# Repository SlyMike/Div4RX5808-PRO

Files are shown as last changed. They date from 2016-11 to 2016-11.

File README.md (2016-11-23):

# Div4RX5808-PRO
Arduino based 5.8GHz  Diversity Video receiver using 2x RX5808-PRO RX modules.

This project requires that you make 3 seperate PCB's. Two RX5808-PRO enabled video RX modules and a Diversity main board.
Boards and schematics are supplied for both the receivers and mainboard. 
Boards and schematics are in Eagle PCB format.

The RX modules will need to be assembled and programmed with the RX5808-PRO software (available on Github).
The diversity code for the Main board is available within this repository. After downloading, replace the .C file extension with .ino and upload.

The Main board and RX modules will require an Arduino Nano with an Atmega328.

The software portion of this project is not an adaptation of RX5808-PRO, it's function is to monitor 2x RSSI inputs from 2x RX5808-PRO enabled receivers and display the video feed from the receiver with the better signal. 
Video, audio and controls are switched simultaniously. LEDs indicate RSSI percentage (4 LEDs), active receiver (2 LEDs) and diversity mode (1 LED).

Holding the "Video" button during boot will allow for RSSI calibration as many RX5808 modules will have slightly different lower and upper limits.
The Div4RX5808-PRO diversity video receiver will assume that channel selection is correct and that nobody else is using the chosen channel.
The transmitter on the RC model should be set to the same channel as the receiver, the model should be powered down.

(1) Turn on Div4RX5808-PRO diversity video receiver in RSSI calibration mode (TX OFF). Amber led indicates LOW RSSI calculation. Press and release "Mode" button.
(2) Turn on transmitter. Second amber led indicates HIGH RSSI calculation. Press and release "Mode" button.
(3) Green LED indicates a good calibration, red a failure.

Auto calibration may not be necessary and if it is not initiated on power up (or fails for some reason), received RSSI values will be directly compared as if limits are equal on both modules.

Hold the "Mode" button during power up to enable serial debug output.

The code has been tested to a degree, it seems to work for me but there is always room for improvement.
I consider this project a work in progress, you may find bugs, spelling mistakes, missing component values, most of the source files were made in a rush or whilst I was doing something else.

I may address this in future but for most folk it should not be hard to build.

The point of this project was to create a decent micro controlled diversity receiver with better features than some of the crude homebrew solutions that I found on the net. I'm pretty sure I met my goal!

      FEATURES:
      
      *** AUTO RSSI CALIBRATION ***
      
      RX5808-PRO SUPPORT.
      
      LIVE VIDEO / SPECTRUM ANALYSER SWITCHING VIA PUSH BUTTON.
      SINGLE RX OR DIVERSITY MODES VIA PUSH BUTTON.
      SERIAL DEBUG MODE VIA PUSH BUTTON.
      TOTAL 6 PUSH BUTTONS FOR EASY OPERATION.
      SOFTWARE SWITCH DE-BOUNCING.
      
      MODE LED INDICATORS.
      RSSI LED INDICATORS.
      RX LED INDICATORS.
      
      VARIABLE RSSI SMOOTHING.
      VARIABLE RX SWITCHING RATE.
      VARIABLE RSSI HYSTERESIS.
      
      CHOICE OF VOLTAGE REFERENCE METHODS - CODE WILL WORK ON 3V3 AND 5V TARGETS.
      WELL COMMENTED CODE.

I hope you find this project helpful, maybe it's worth a coffee?              


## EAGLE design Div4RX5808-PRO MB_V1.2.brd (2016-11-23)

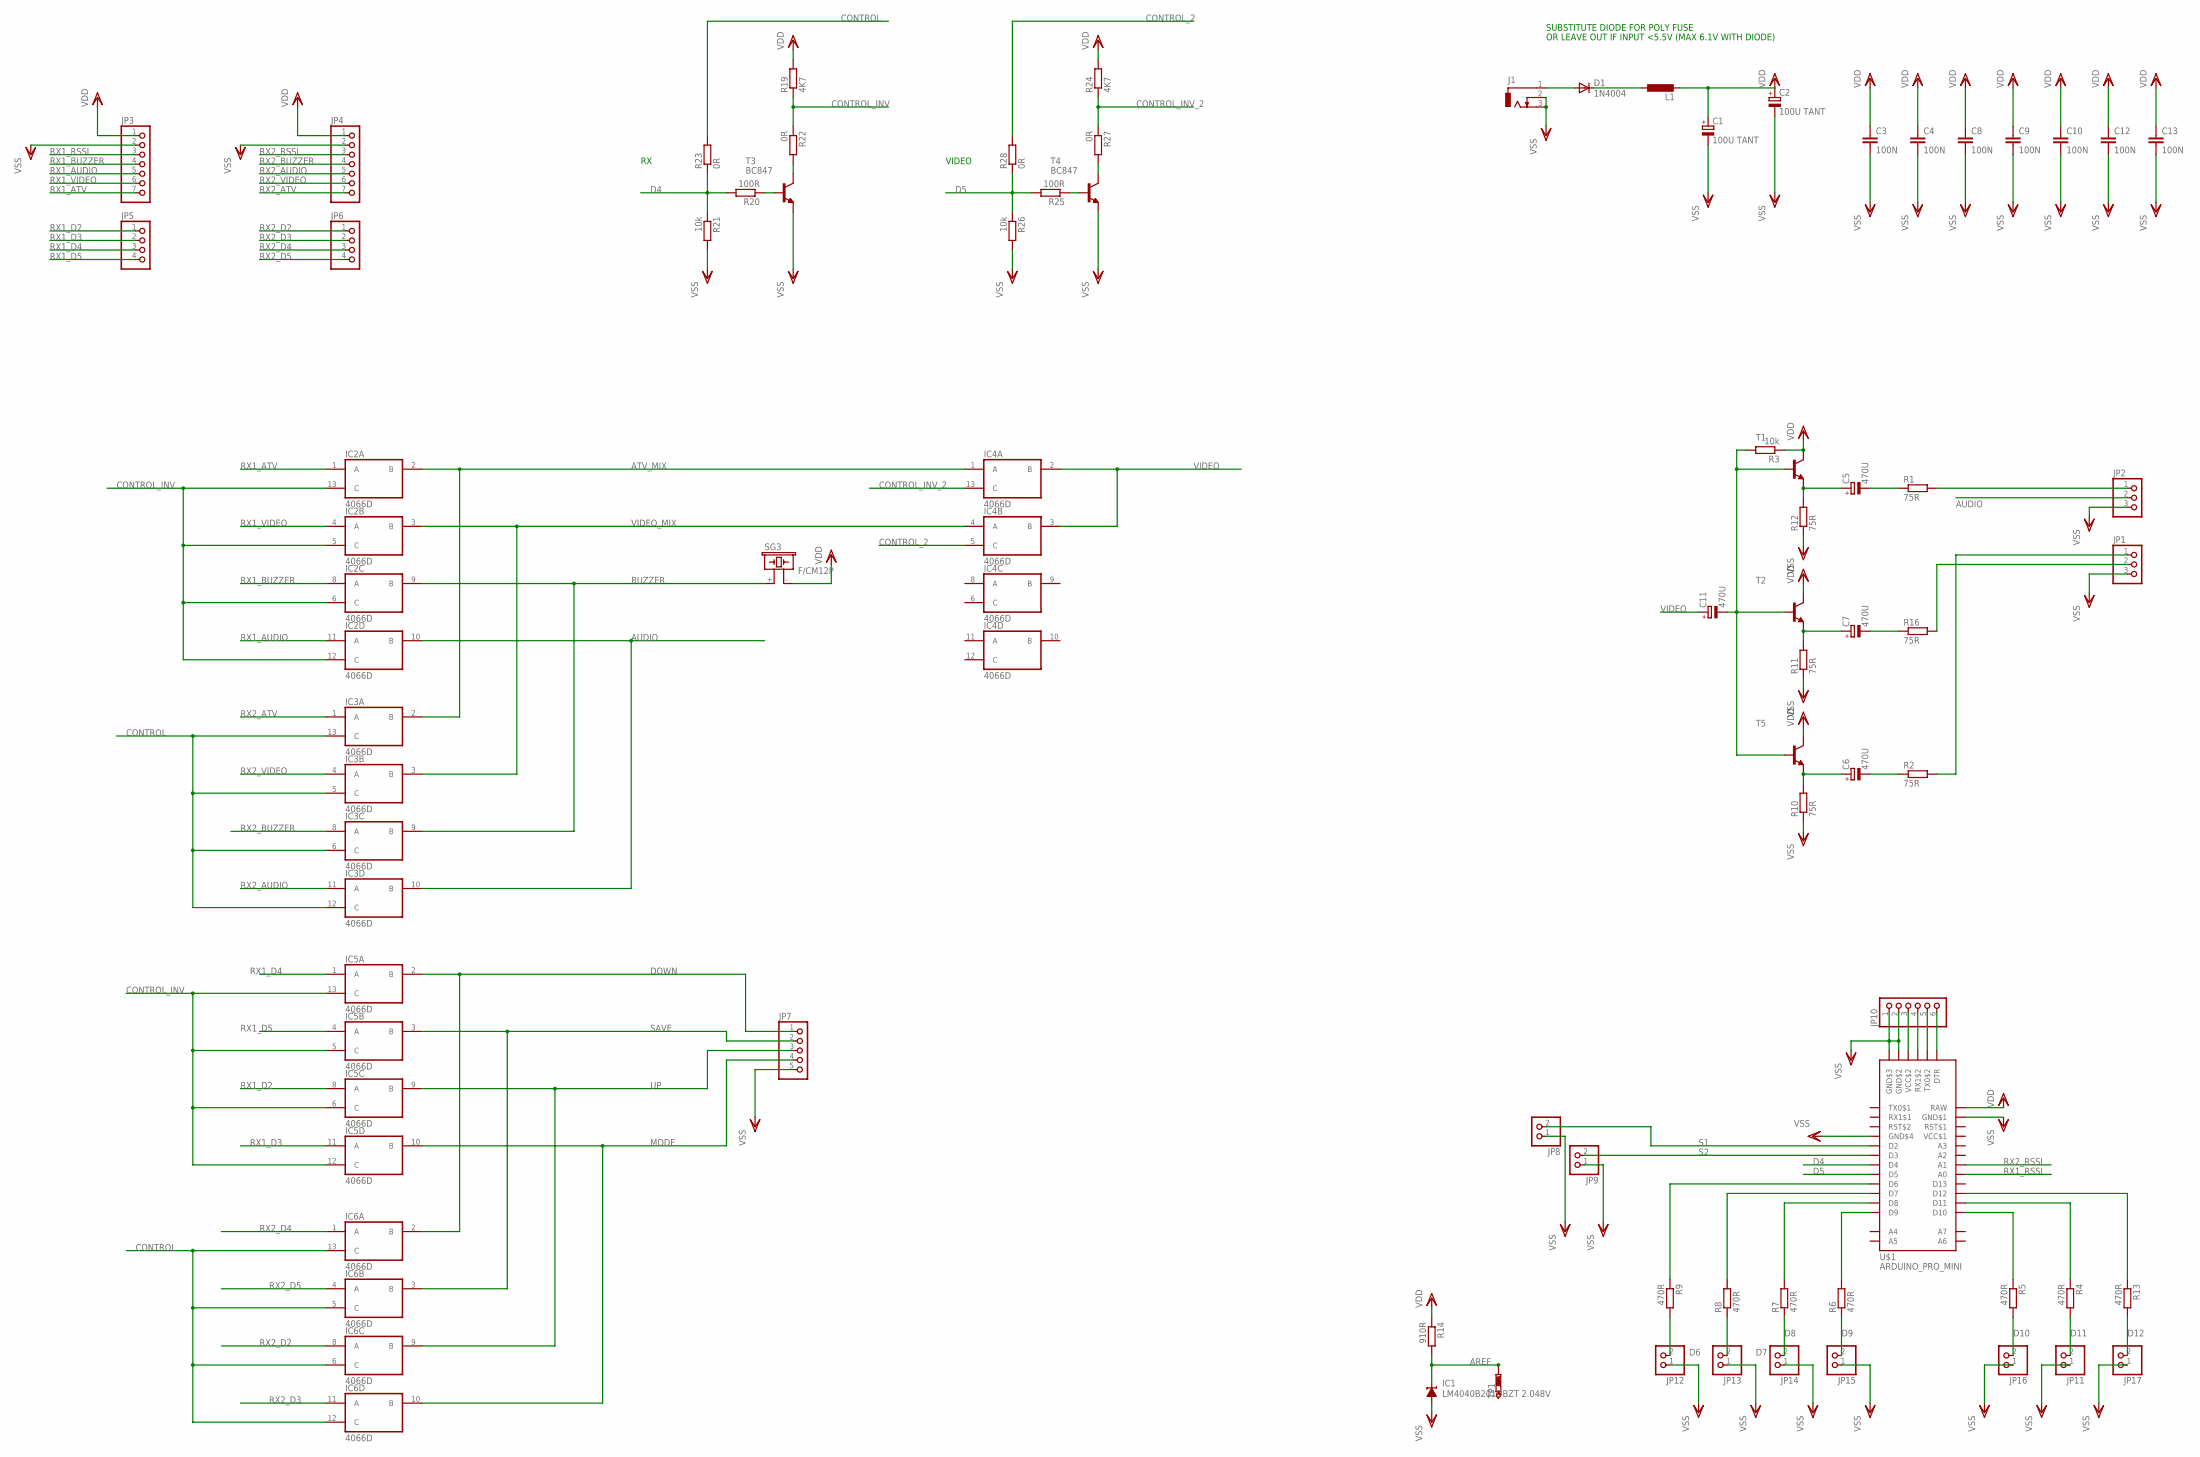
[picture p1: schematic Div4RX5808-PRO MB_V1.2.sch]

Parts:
C1, C2: 100U TANT; C/6032-28R
C3, C4, C8, C9, C10, C12, C13: 100N; C0603
C5, C6, C7, C11: 470U; E5-10,5
D1: 1N4004; DO41-10
IC1: LM4040B201DBZT 2.048V; DBZ_R-PDSO-G3
IC2, IC3, IC4, IC5, IC6: 4066D; SO14
J1: DCJ0303
JP1, JP2: PINHD-1X3; 1X03
JP3, JP4: PINHD-1X7; 1X07
JP5, JP6: PINHD-1X4; 1X04
JP7: PINHD-1X5; 1X05
JP8, JP9, JP11, JP12, JP13, JP14, JP15, JP16, JP17: PINHD-1X2; 1X02
JP10: PINHD-1X6; 1X06
L1: L-EU0207/7; 0207/7
R1, R2, R10, R11, R12, R16: 75R; M0805
R3, R21, R26: 10k; M0805
R4, R5, R6, R7, R8, R9, R13: 470R; R0603
R14: 910R; R0603
R19, R24: 4K7; M0805
R20, R25: 100R; M0805
R22, R23, R27, R28: 0R; M0805
SG3: F/CM12P
T1, T2, T5: MMBT2222ALT1-NPN-SOT23-BEC; SOT23-BEC
T3, T4: BC847; SOT23-BEC
TP1: PTR1TP20SQ; TP20SQ
U$1: ARDUINO_PRO_MINI

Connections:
AREF: IC1.1 (C), R14.2, TP1.TP
ATV_MIX: IC2.2 (B), IC3.2 (B), IC4.1 (A)
AUDIO: IC2.10 (B), IC3.10 (B), JP2.2
BUZZER: IC2.9 (B), IC3.9 (B), SG3.+ (1)
CONTROL: IC3.5 (C), IC3.6 (C), IC3.12 (C), IC3.13 (C), IC6.5 (C), IC6.6 (C), IC6.12 (C), IC6.13 (C), R23.2
CONTROL_2: IC4.5 (C), R28.2
CONTROL_INV: IC2.5 (C), IC2.6 (C), IC2.12 (C), IC2.13 (C), IC5.5 (C), IC5.6 (C), IC5.12 (C), IC5.13 (C), R19.1, R22.1
CONTROL_INV_2: IC4.13 (C), R24.1, R27.1
D4: R20.2, R21.1, R23.1, U$1.D4
D5: R25.2, R26.1, R28.1, U$1.D5
D6: JP12.2, R9.2
D7: JP13.2, R8.1
D8: JP14.2, R7.1
D9: JP15.2, R6.1
D10: JP16.2, R5.2
D11: JP11.2, R4.2
D12: JP17.2, R13.2
DOWN: IC5.2 (B), IC6.2 (B), JP7.1
MODE: IC5.10 (B), IC6.10 (B), JP7.4
unnamed: D1.C, L1.1
unnamed: D1.A, J1.1
unnamed: R13.1, U$1.D12
unnamed: C5.-, R1.1
unnamed: C6.-, R2.1
unnamed: JP2.1, R1.2
unnamed: C7.-, R16.1
unnamed: JP1.2, R16.2
unnamed: JP1.1, R2.2
unnamed: C5.+, R12.2, T1.E
unnamed: JP10.6, U$1.DTR
unnamed: JP10.5, U$1.TX0$2
unnamed: C7.+, R11.2, T2.E
unnamed: JP10.4, U$1.RX1$2
unnamed: JP10.3, U$1.VCC$2
unnamed: R25.1, T4.B
unnamed: C6.+, R10.2, T5.E
unnamed: R22.2, T3.C
unnamed: R20.1, T3.B
unnamed: R27.2, T4.C
unnamed: C11.-, R3.2, T1.B, T2.B, T5.B
unnamed: R9.1, U$1.D6
unnamed: R8.2, U$1.D7
unnamed: R6.2, U$1.D9
unnamed: R4.1, U$1.D11
unnamed: R5.1, U$1.D10
unnamed: R7.2, U$1.D8
RX1_ATV: IC2.1 (A), JP3.7
RX1_AUDIO: IC2.11 (A), JP3.5
RX1_BUZZER: IC2.8 (A), JP3.4
RX1_D2: IC5.8 (A), JP5.1
RX1_D3: IC5.11 (A), JP5.2
RX1_D4: IC5.1 (A), JP5.3
RX1_D5: IC5.4 (A), JP5.4
RX1_RSSI: JP3.3, U$1.A0
RX1_VIDEO: IC2.4 (A), JP3.6
RX2_ATV: IC3.1 (A), JP4.7
RX2_AUDIO: IC3.11 (A), JP4.5
RX2_BUZZER: IC3.8 (A), JP4.4
RX2_D2: IC6.8 (A), JP6.1
RX2_D3: IC6.11 (A), JP6.2
RX2_D4: IC6.1 (A), JP6.3
RX2_D5: IC6.4 (A), JP6.4
RX2_RSSI: JP4.3, U$1.A1
RX2_VIDEO: IC3.4 (A), JP4.6
S1: JP8.2, U$1.D2
S2: JP9.2, U$1.D3
SAVE: IC5.3 (B), IC6.3 (B), JP7.2
UP: IC5.9 (B), IC6.9 (B), JP7.3
VCC$1: U$1.VCC$1
VDD: C1.+, C2.+, C3.1, C4.1, C8.1, C9.1, C10.1, C12.1, C13.1, IC2.14 (VDD), IC3.14 (VDD), IC4.14 (VDD), IC5.14 (VDD), IC6.14 (VDD), JP3.1, JP4.1, L1.2, R3.1, R14.1, R19.2, R24.2, SG3.- (2), T1.C, T2.C, T5.C, U$1.RAW
VIDEO: C11.+, IC4.2 (B), IC4.3 (B)
VIDEO_MIX: IC2.3 (B), IC3.3 (B), IC4.4 (A)
VSS: C1.-, C2.-, C3.2, C4.2, C8.2, C9.2, C10.2, C12.2, C13.2, IC1.2 (A), IC2.7 (VSS), IC3.7 (VSS), IC4.7 (VSS), IC5.7 (VSS), IC6.7 (VSS), J1.2, J1.3, JP1.3, JP2.3, JP3.2, JP4.2, JP7.5, JP8.1, JP9.1, JP10.1, JP10.2, JP11.1, JP12.1, JP13.1, JP14.1, JP15.1, JP16.1, JP17.1, R10.1, R11.1, R12.1, R21.2, R26.2, T3.E, T4.E, U$1.GDN$1 (GND$1), U$1.GND$2, U$1.GND$3, U$1.GND$4

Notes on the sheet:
VIDEO
SUBSTITUTE DIODE FOR POLY FUSE
OR LEAVE OUT IF INPUT <5.5V (MAX 6.1V WITH DIODE)

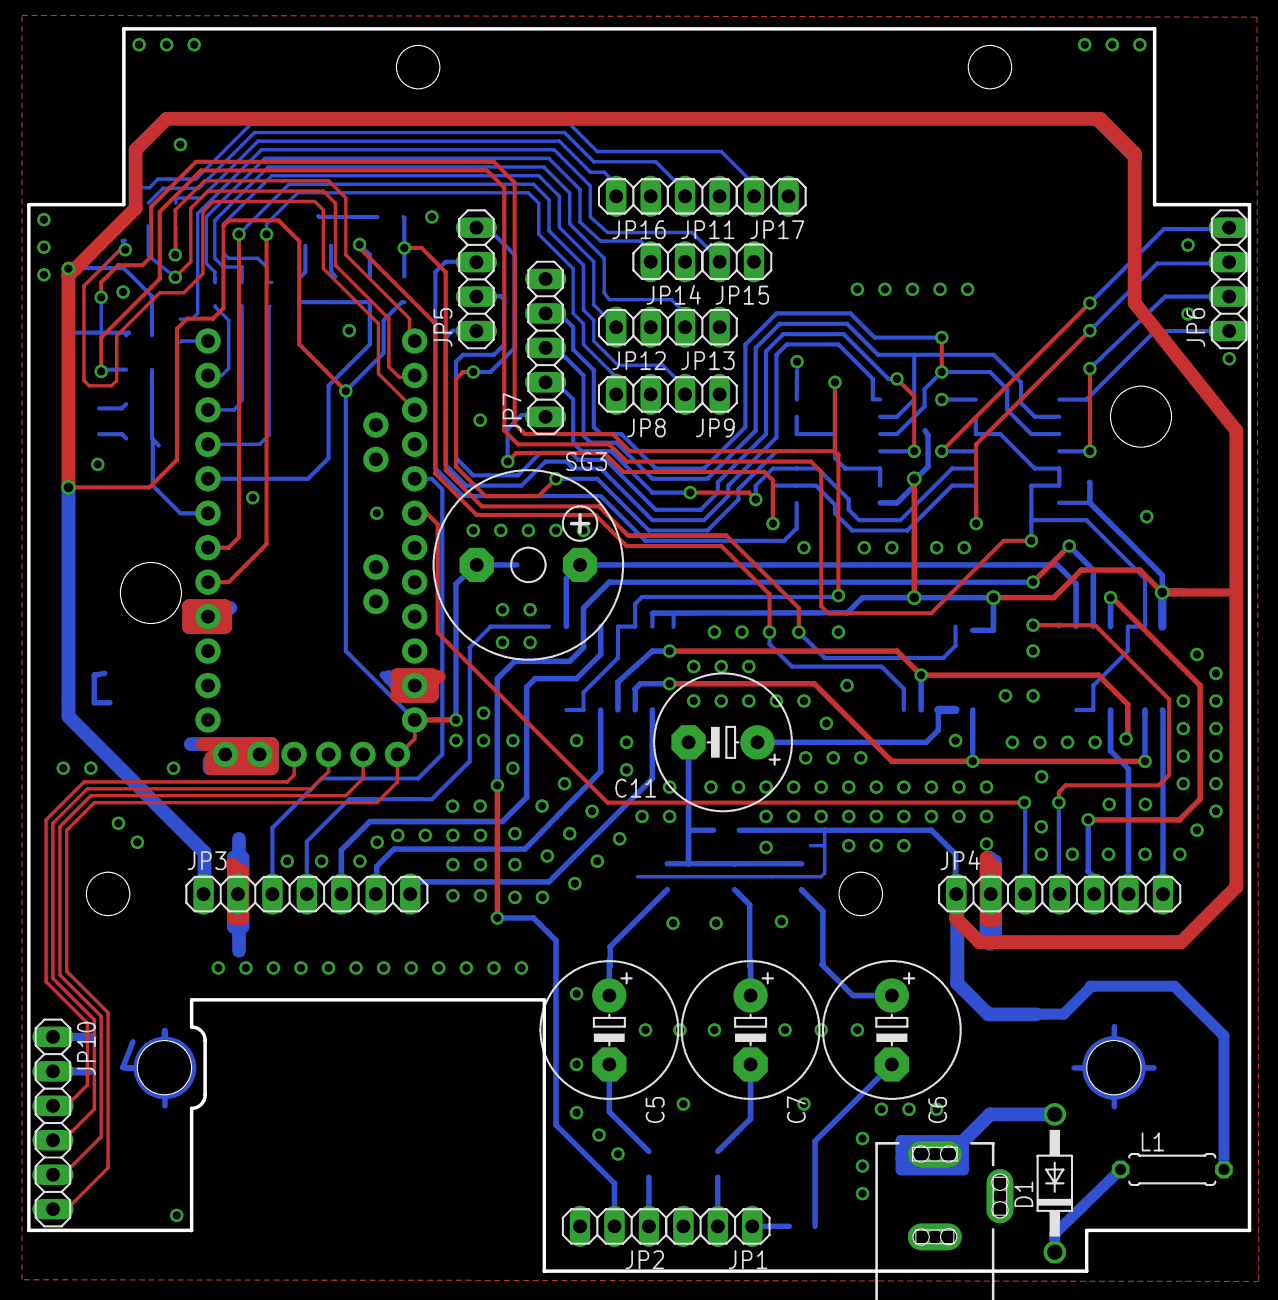
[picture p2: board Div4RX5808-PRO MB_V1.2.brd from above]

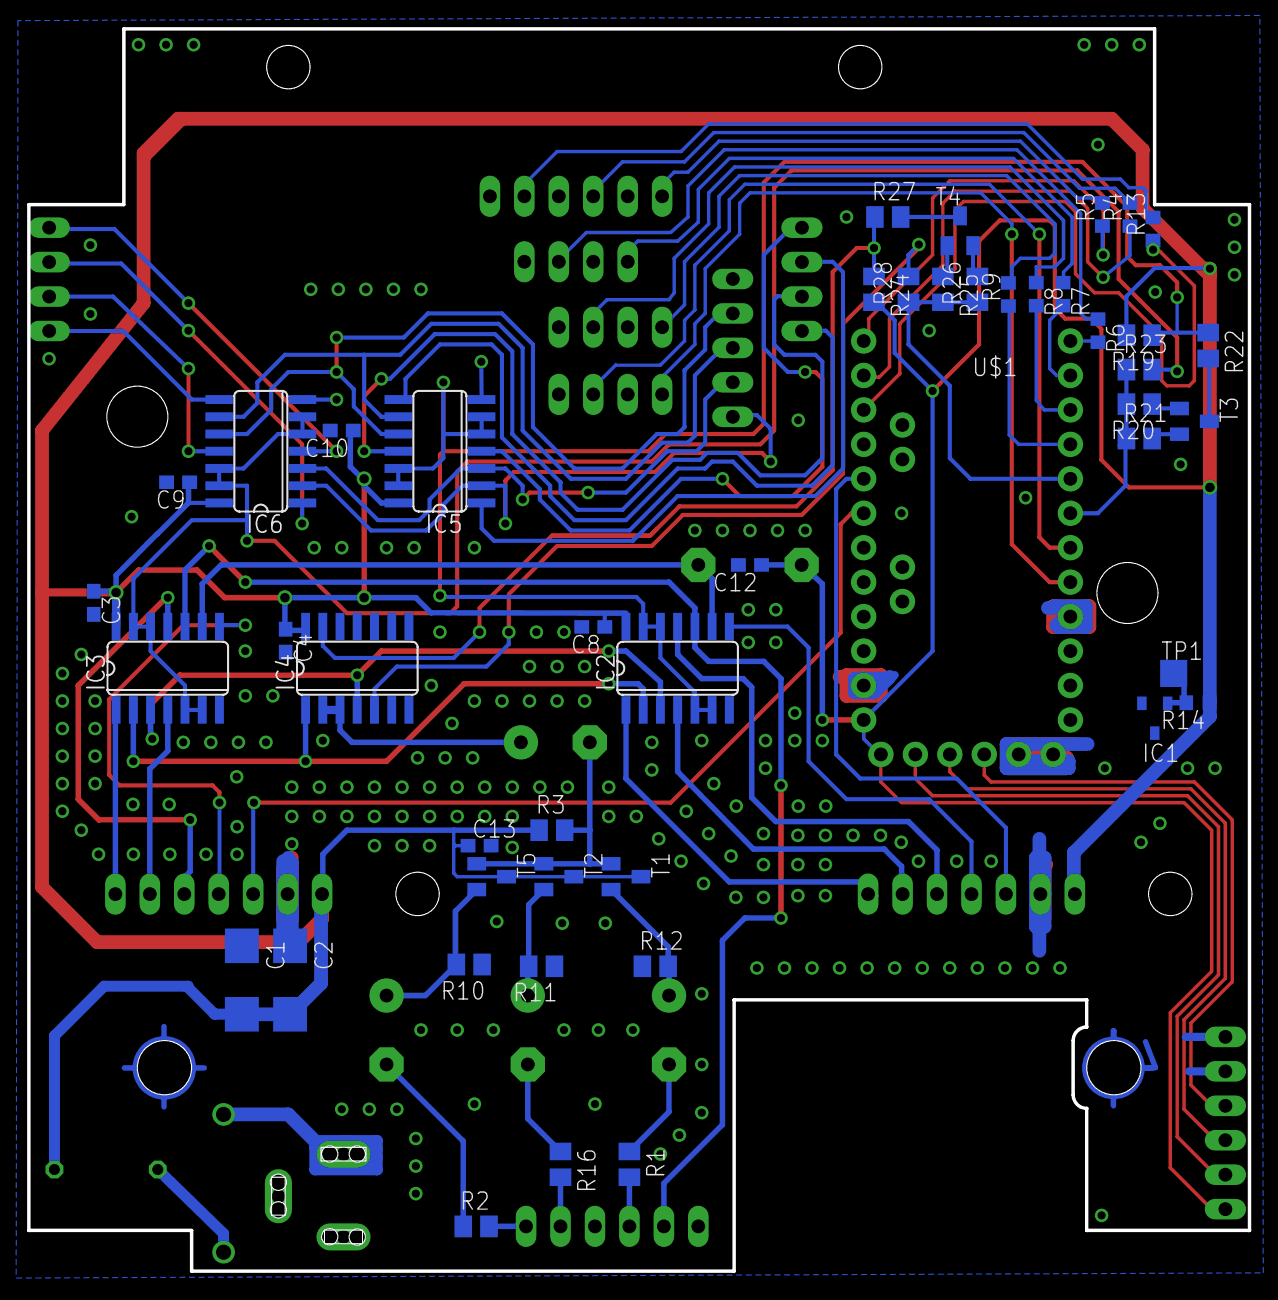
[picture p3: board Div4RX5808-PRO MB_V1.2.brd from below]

Board: 2 copper layers, 90.0 x 91.6 mm, 72 parts (47 on the bottom side), 72 nets.

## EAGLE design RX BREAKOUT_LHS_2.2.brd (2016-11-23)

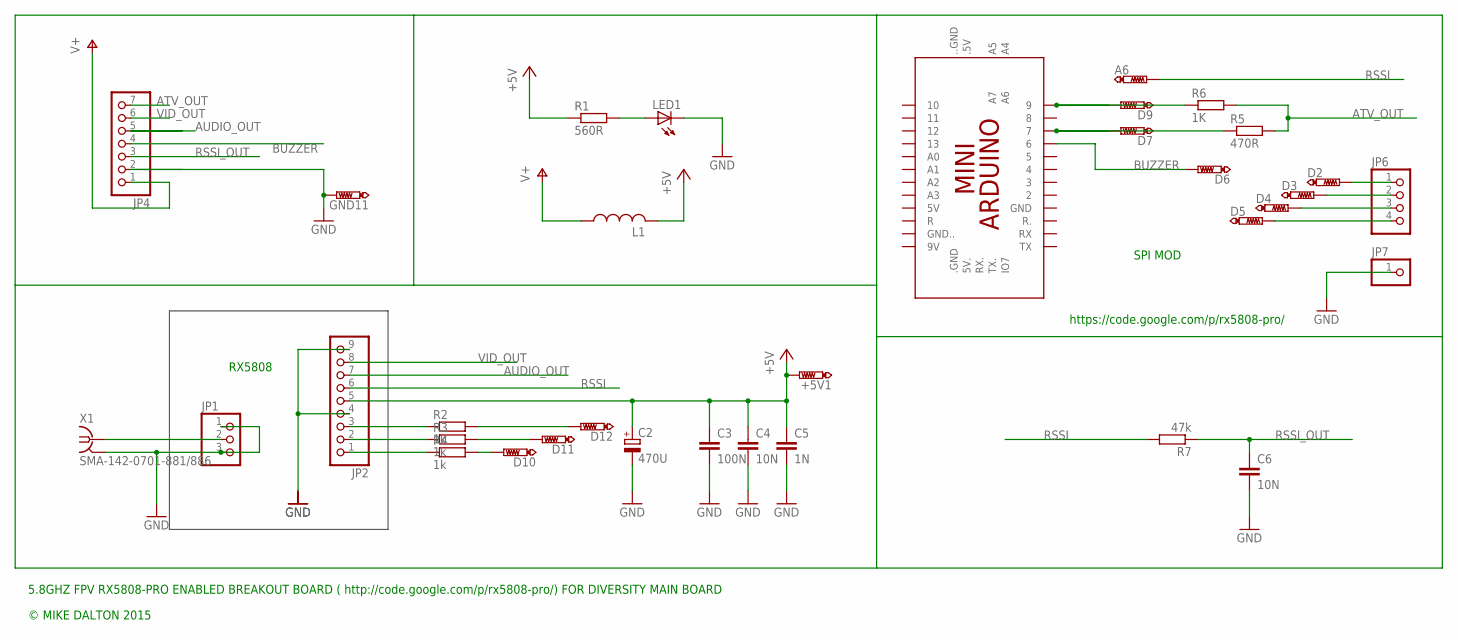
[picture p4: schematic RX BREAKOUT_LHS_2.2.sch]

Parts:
+5V1: PTR1TP16SQ; TP16SQ
A6: PTR1TP16SQ; TP16SQ
C2: 470U; E5-10,5
C3: 100N; C0603K
C4, C6: 10N; C0603K
C5: 1N; C0603K
D2, D3, D4, D5, D6, D7, D9, D10, D11, D12: PTR1TP16SQ; TP16SQ
GND11: PTR1TP16SQ; TP16SQ
JP1: PINHD-1X3; 1X03
JP2: PINHD-1X9; 1X09
JP4: PINHD-1X7; 1X07
JP6: PINHD-1X4; 1X04
JP7: PINHD-1X1; 1X01
L1: L-USL4532C; L4532M
LED1: LEDSMT1206; 1206
R1: 560R; R0603
R2, R3, R4: 1k; R0603
R5: 470R; R0603
R6: 1K; R0603
R7: 47k; R0603
X1: SMA-142-0701-881/886; J502-ND-142-0701-881/886

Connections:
ATV_OUT: JP4.7, R5.2, R6.2
AUDIO_OUT: JP2.7, JP4.5
BUZZER: D6.TP, JP4.4
D7: D7.TP, R5.1
D9: D9.TP, R6.1
GND: C2.-, C3.2, C4.2, C5.2, C6.2, GND11.TP, JP1.1, JP1.3, JP2.4, JP2.9, JP4.2, JP7.1, LED1.C, X1.G@1 (2), X1.G@2 (2), X1.G@3 (2), X1.G@4 (2)
unnamed: D12.TP, R2.2
unnamed: JP2.3, R2.1
unnamed: D11.TP, R3.2
unnamed: LED1.A, R1.2
unnamed: JP1.2, X1.1
unnamed: D10.TP, R4.2
unnamed: JP2.2, R3.1
unnamed: +5V1.TP, C2.+, C3.1, C4.1, C5.1, JP2.5, L1.2, R1.1
unnamed: JP2.1, R4.1
unnamed: D2.TP, JP6.1
unnamed: D3.TP, JP6.2
unnamed: D4.TP, JP6.3
unnamed: D5.TP, JP6.4
RSSI: A6.TP, JP2.6, R7.2
RSSI_OUT: C6.1, JP4.3, R7.1
V+: JP4.1, L1.1
VID_OUT: JP2.8, JP4.6

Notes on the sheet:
RX5808
SPI MOD
https://code.google.com/p/rx5808-pro/
© MIKE DALTON 2015
5.8GHZ FPV RX5808-PRO ENABLED BREAKOUT BOARD ( http://code.google.com/p/rx5808-pro/) FOR DIVERSITY MAIN BOARD

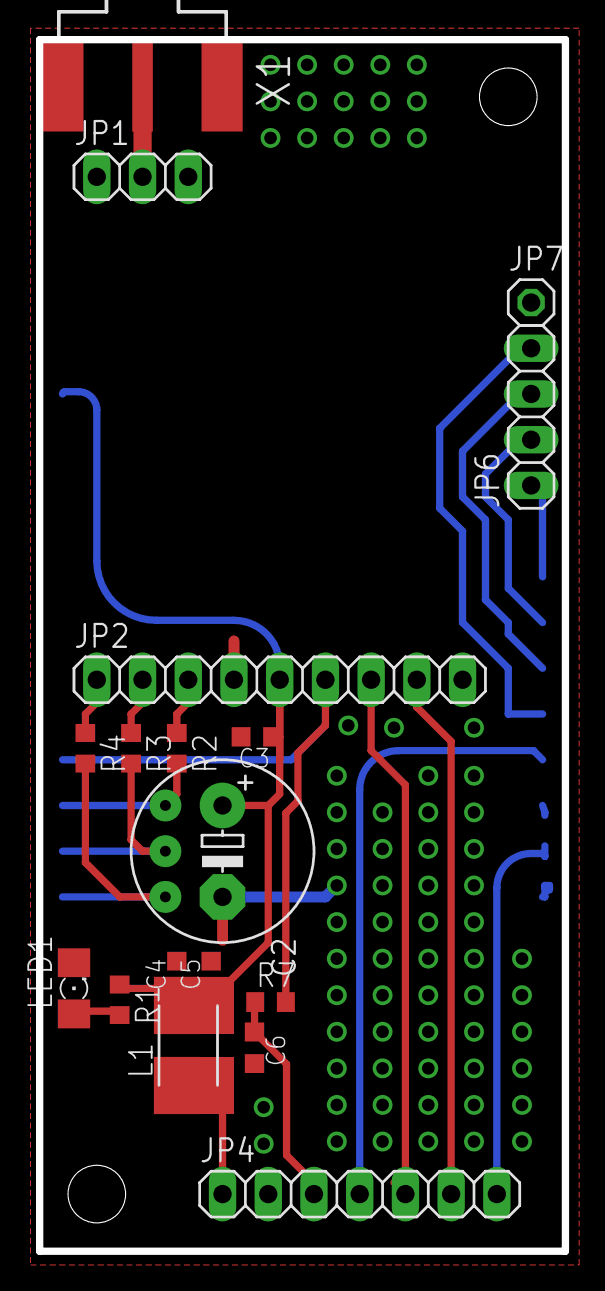
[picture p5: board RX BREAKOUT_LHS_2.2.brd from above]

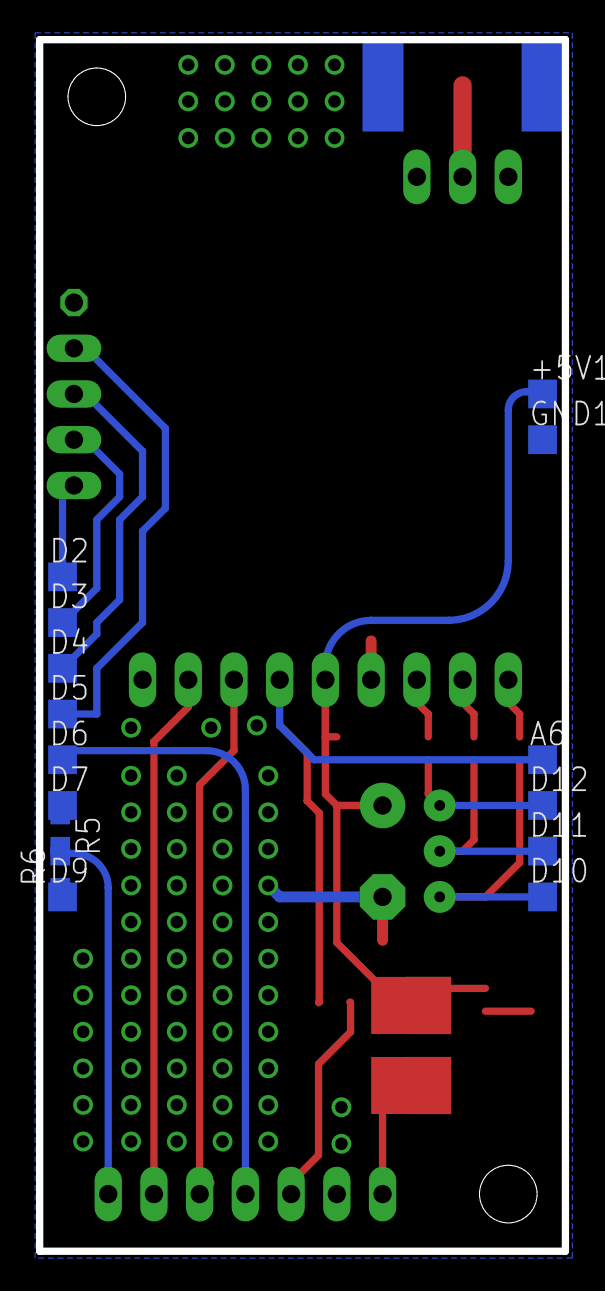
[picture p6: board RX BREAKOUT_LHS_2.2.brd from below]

Board: 2 copper layers, 29.2 x 67.3 mm, 33 parts (15 on the bottom side), 23 nets.

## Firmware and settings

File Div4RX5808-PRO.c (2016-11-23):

/*****************************************************************************
 Dual 5.8ghz Video Receiver Diversity Controller with RX5808-PRO functionality.
 "Div4RX5808-PRO"
 Mike Dalton 2015

 RC VIDEO RECEIVER SOFTWARE FOR ATMEGA328.

 RX5808-PRO SUPPORT!
 LIVE VIDEO / SPECTRUM ANALYSER SWITCHING VIA PUSH BUTTON!
 SINGLE RX OR DIVERSITY MODES VIA PUSH BUTTON!
 SERIAL DEBUG MODE VIA PUSH BUTTON!
 MODE LED INDICATORS!
 SOFTWARE SWITCH DE-BOUNCING!
 VARIABLE SOFTWARE RSSI SMOOTHING!
 RSSI VALUES VIA 4 LEDS!
 VARIABLE RX SWITCHING RATE!
 AUTO RSSI CALIBRATION!


 Physical pins used:

 A0      RSSI1_ADC_PIN           ANALOGUE INPUT    left channel RSSI input (RX1, 0.5V-1.2V).
 A1      RSSI2_ADC_PIN           ANALOGUE INPUT    right channel RSSI input (RX2, 0.5V-1.2V).
 A2      N/A                     N/A               N/A
 A3      N/A                     N/A               N/A
 A4      N/A                     N/A               N/A
 A5      N/A                     N/A               N/A
 A6      N/A                     N/A               N/A
 A7      N/A                     N/A               N/A
 D0      SERIAL                  TX                Serial connection
 D1      SERIAL                  RX                Serial connection
 D2      MODE_SWITCH             INPUT PULLUP      Switch 1, Mode select between left channel, right channel and diversity using RSSI. (ENTERS DEBUG MODE AT POWER UP)
 D3      VIDEO_SWITCH            INPUT PULLUP      Switch 2, selects between live video output from selected receiver and ATV (spectrum analyser) output from RX8505-PRO board.
 D4      RX_CONTROL_PIN          OUTPUT            Pin to control switching between receiver 1 and 2, default LOW - RX1.
 D5      VIDEO_CONTROL_PIN       OUTPUT            Pin to control switching between live video and ATV. (ATV = Arduino TV out - SPECTRUM ANALYSER)
 D6      LED_RX_1                OUTPUT            LED for RX1 radio.
 D7      LED_RX_2                OUTPUT            LED for RX2 radio.
 D8      LED_025_P               OUTPUT            RED LED to display RSSI between 0%-25%.
 D9      LED_050_P               OUTPUT            AMBER LED to display RSSI between 26$-50%.
 D10     LED_075_P               OUTPUT            AMBER LED to display RSSI between 51%-75%.
 D11     LED_100_P               OUTPUT            GREEN LED to display RSSI between 76%-100%
 D12     LED_DIVERSITY           OUTPUT            GREEN LED to display if Diversity is Enabled.
 D13     LED_HEARTBEAT           OUTPUT            HEART BEAT LED
 AREF    (OPTION)                (INPUT)           (OPTIONAL VOLTAGE REFERENCE TO INCREASE RESOLUTION FOR RX THAT USE RSSI >1.1V).


 The main settings to change the behaviour of the unit:

 BUTTON_DEBOUNCE_MILLIS          Alters repeat speed of push buttons.
 MAX_AVERAGE_READINGS            Smoothing value for taking average RSSI readings.
 RSSI_HYSTERESIS                 Overhead for RSSI signal (RX switching) in diversity mode.
 DIVERSITY_INTERVAL_MILLIS       Minimum value, in milliseconds to toggle receivers.

 RSSI1Min, RSSI1Max              The default expected ADC readings for your RX.
 RSSI2Min, RSSI2Max              The default expected ADC readings for your RX.

 CALIB_TIMEOUT_MILLIS            Time between starting Auto Calibration and giving up.
 ONE_TIME_WARMUP_DELAY           The amount of time you expect your TX gear (RC model) to take to settle in after power up.
 *******************************************************************************/



/* Physical pin assignments. */
#define RSSI1_ADC_PIN A0                                /* ADC connected to reciever 1 RSSI output pin. */
#define RSSI2_ADC_PIN A1                                /* ADC connected to reciever 2 RSSI output pin. */
#define MODE_SWITCH 2                                   /* Press this button to switch between available RX modes. */
#define VIDEO_SWITCH 3                                  /* Press this button to switch between live video and spectrum analyser. */
#define RX_CONTROL_PIN 4                                /* Toggled by software to select RX unit. */
#define VIDEO_CONTROL_PIN 5                             /* Toggled by software to select between live video and spectrum analyser. */

/* LEDs. */
#define LED_RX_1 6                                      /* RX1 status LED. */
#define LED_RX_2 7                                      /* RX2 status LED. */
#define LED_025_P 8                                     /* RSSI 0%-25% status LED. */
#define LED_050_P 9                                     /* RSSI 26%-50% status LED. */
#define LED_075_P 10                                    /* RSSI 51%-75% status LED. */
#define LED_100_P 11                                    /* RSSI 76%-100% status LED. */
#define LED_DIVERSITY 12                                /* Diversity active indicator LED. */
#define LED_HEARTBEAT 13                                /* Heartbeat, indicates loop speed, for initial debug. */

/* Delays. */
#define ADC_WARMUP_DELAY 1                              /* Time to let ADCs settle. Default 1. */
#define BUTTON_DEBOUNCE_MILLIS 250                      /* Push button debounce value. Default 250. */
#define DIVERSITY_INTERVAL_MILLIS 2000                  /* Minimum allowable time before video pin toggles. Default 500. */
#define CALIB_STAB_CYCLES 1000                          /* Calibration stabilization cycles. Give pleanty of cycles for averages to become stable figures. Default 1000. */
#define CALIB_TIMEOUT_MILLIS 30000                      /* Give up calibrating after X seconds. Default 30000. */
#define ONE_TIME_WARMUP_DELAY 5000                      /* A one time delay to allow voltages to stabilize on the TX and RC model during Auto Calibration. Default 5000. */
#define CALIB_RETRY_INITIAL_DELAY 10000                 /* Wait period before starting calibration after first attempt fails. Default 5000. */

/* Info. */
#define AUTHOR "MIKE DALTON"                            /* Version info. */
#define INFO_MAJOR_VERSION "1"                          /* Version info. */
#define INFO_MINOR_VERSION "9"                          /* Version info. */
#define COMPILE_TIME __TIME__                           /* Version info. */
#define COMPILE_DATE __DATE__                           /* Version info. */
#define SOURCE_FILE __FILE__                            /* Version info. */
#define COMPILER __VERSION__                            /* Version info. */

/* RSSI. */
#define MAX_AVERAGE_READINGS 10                         /* Smoothing value for RSSI averages. Default 10. */
#define RSSI_HYSTERESIS 1                               /* This hysteresis value is a % of the calculated RSSI value. Default 1. */

                                                        /* RSSI voltage range is between 0.5v and 1.1v for most rx5808 modules. */
unsigned int RSSI1Min = 512;                            /* Default 512. */
unsigned int RSSI1Max = 1023;                           /* 1024 = 1.1V when using internal voltage reference. Default 1024. */
unsigned int RSSI2Min = 512;                            /* Default 512. */
unsigned int RSSI2Max = 1023;                           /* 1024 = 1.1V when using internal voltage reference. Default 1024. */
int RSSI1P = 0;                                         /* Mapped RSSI value as a percentage - taken from min and max values. */
int RSSI2P = 0;                                         /* Mapped RSSI value as a percentage - taken from min and max values. */
unsigned int RSSI1Readings[MAX_AVERAGE_READINGS];       /* The readings from the analogue input. */
unsigned int RSSI1ReadIndex = 0;                        /* The index of the current reading. */
unsigned int RSSI1Total = 0;                            /* The running total. */
unsigned int RSSI1Average = 0;                          /* The average RSSI. */
unsigned int RSSI1InputPinValue = 0;                    /* ADC reading. */
unsigned int RSSI2Readings[MAX_AVERAGE_READINGS];       /* The readings from the analogue input. */
unsigned int RSSI2ReadIndex = 0;                        /* The index of the current reading. */
unsigned int RSSI2Total = 0;                            /* The running total. */
unsigned int RSSI2Average = 0;                          /* The average RSSI. */
unsigned int RSSI2InputPinValue = 0;                    /* ADC reading. */

/* Voltage. */
float ADC_MAX = 1024.0;                                 /* Max ADC value. */
float RSSIARef = 1.1;                                   /* Voltage of selected analogue reference. (see below, setup) */
float RSSI1Volts = 0;                                   /* Calculated voltage on RSSI pin. */
float RSSI2Volts = 0;                                   /* Calculated voltage on RSSI pin. */

/* Buttons. */
int VideoControlPinState = LOW;                         /* The current state of the output pin. */
int VideoSwitchCounter = 1;                             /* Counter for mode selection. */
int VideoSwitchReading;                                 /* The current reading from the input pin. */
int VideoSwitchPrevious = HIGH;                         /* The previous reading from the input pin. */
long VideoSwitchTime = 0;                               /* The last time the output pin was toggled. */

int RxControlPinState = LOW;                            /* The current state of the output pin. */
int ModeSwitchCounter = 1;                              /* Counter for mode selection - 3 modes. (mode 1= rx1, mode 2= rx2, mode 3= diversity) */
int ModeSwitchReading;                                  /* The current reading from the input pin. */
long ModeSwitchTime = 0;                                /* The last time the output pin was toggled. */

/* Flags. */
boolean DebugMode = false;                              /* State of debug mode. */
boolean AutoRSSIMode = false;                           /* State of auto RSSI mode. */
boolean MinRSSICalibrationFlag = false;                 /* False = fail, true = pass. */
boolean MaxRSSICalibrationFlag = false;                 /* False = fail, true = pass. */
boolean MinCalibRunOnce = false;
boolean MaxCalibRunOnce = false;
boolean RSSICalibrationCompleteFlag = false;            /* Set after both RSSI figures have been updated with on the fly values. */
boolean OneTimeWarmupDelayFlag = true;                  /* True until one cycle of auto calibration of high RSSI has been attempted. */
boolean CalibRetryDelayFlag = false;                    /* Initiate a delay before restarting Recalibration. */
boolean RecalibrateButtonCheck = true;                  /* Check for a button press to initiate a recalibration cycle. */
boolean Recalibrate = false;                            /* Enter Recalibration function. */
boolean StartMinCal = false;
boolean MincalibrateButtonCheck = true;
boolean StartMaxCal = false;
boolean MaxcalibrateButtonCheck = true;


/* Diversity. */
unsigned long CounterPreviousDiversitySwitchTime = 0;   /* Counter for DIVERSITY_INTERVAL_MILLIS. */
unsigned int AutoRSSICalLowLevel = 40;                  /* % RSSI FOR AUTO CAL. Default 30. */
unsigned int AutoRSSICalHighLevel = 60;                 /* % RSSI FOR AUTO CAL. Default 70. */
unsigned int RSSI1TempMin = 0;                          /* Used during auto calibration. */
unsigned int RSSI1TempMax = 0;                          /* Used during auto calibration. */
unsigned int RSSI2TempMin = 0;                          /* Used during auto calibration. */
unsigned int RSSI2TempMax = 0;                          /* Used during auto calibration. */

/* Calibration. */
unsigned int CalibrationCyclesCounter = 0;              /* Counter to make sure average RSSI readings have stabilized during calibration. */
unsigned long CalibrationTimeoutCounter = 0;            /* Allow us to bail out of auto calibration if readings aren't within specification. */
unsigned long RecalibrationOffsetCounter = 0;


void setup() {

    pinMode(RSSI1_ADC_PIN, INPUT);
    pinMode(RSSI2_ADC_PIN, INPUT);

    pinMode(MODE_SWITCH, INPUT_PULLUP);                 /* Hold during power up to enter debug mode. */
    pinMode(VIDEO_SWITCH, INPUT_PULLUP);                /* Hold during power up to enter auto RSSI calibration mode mode. */
                                                        /* Both buttons can be held simultaneously. */
    pinMode(RX_CONTROL_PIN, OUTPUT);
    pinMode(VIDEO_CONTROL_PIN, OUTPUT);

    pinMode(LED_RX_1, OUTPUT);
    pinMode(LED_RX_2, OUTPUT);

    pinMode(LED_025_P, OUTPUT);
    pinMode(LED_050_P, OUTPUT);
    pinMode(LED_075_P, OUTPUT);
    pinMode(LED_100_P, OUTPUT);

    pinMode(LED_DIVERSITY, OUTPUT);
    pinMode(LED_HEARTBEAT, OUTPUT);


    analogReference(INTERNAL);   /* Use internal 1V1 reference. */
    //analogReference(DEFAULT);  /* Use supply voltage as reference. (3V3 / 5V) */
    //analogReference(EXTERNAL); /* Use a voltage reference IC of your choice on the AREF pin. (EXAMPLE = FARNELL.COM:175-5111 / LM4040B20IDBZT) */
    /* The exact figure must be entered into "RSSIARef" in the Voltage section above to calculate correct debug info. */

    /* Warm up ADCs */
    RSSI1InputPinValue = analogRead(RSSI1_ADC_PIN);
    delay(ADC_WARMUP_DELAY);
    RSSI1InputPinValue = analogRead(RSSI1_ADC_PIN);
    delay(ADC_WARMUP_DELAY);
    RSSI1InputPinValue = analogRead(RSSI1_ADC_PIN);
    delay(ADC_WARMUP_DELAY);
    RSSI2InputPinValue = analogRead(RSSI2_ADC_PIN);
    delay(ADC_WARMUP_DELAY);
    RSSI2InputPinValue = analogRead(RSSI2_ADC_PIN);
    delay(ADC_WARMUP_DELAY);
    RSSI2InputPinValue = analogRead(RSSI2_ADC_PIN);
    delay(ADC_WARMUP_DELAY);

    /* RSSI averaging setup */
    for(int ReadingCurrent = 0; ReadingCurrent < MAX_AVERAGE_READINGS; ReadingCurrent++)
    {
        RSSI1Readings[ReadingCurrent] = 0;
        RSSI2Readings[ReadingCurrent] = 0;
    }

    digitalWrite(RX_CONTROL_PIN, LOW);        /* Default RX module on start-up. */
    digitalWrite(VIDEO_CONTROL_PIN, LOW);     /* Default screen (live video / spectrum analyser) on start-up. */

    digitalWrite(LED_025_P, HIGH);            /* flash some LEDs. */
    delay(150);
    digitalWrite(LED_050_P, HIGH);
    delay(150);
    digitalWrite(LED_075_P, HIGH);
    delay(150);
    digitalWrite(LED_100_P, HIGH);
    delay(150);
    digitalWrite(LED_RX_1, HIGH);
    digitalWrite(LED_RX_2, HIGH);
    digitalWrite(LED_DIVERSITY, HIGH);
    delay(100);
    digitalWrite(LED_025_P, LOW);
    digitalWrite(LED_050_P, LOW);
    digitalWrite(LED_075_P, LOW);
    digitalWrite(LED_100_P, LOW);
    digitalWrite(LED_RX_1, LOW);
    digitalWrite(LED_RX_2, LOW);
    digitalWrite(LED_DIVERSITY, LOW);


    if (digitalRead(MODE_SWITCH) == 0)         /* Holding Mode switch enters DebugMode. */
    {
        DebugMode = true;
    }

    else
    {
        DebugMode = false;
    }

    if (digitalRead(VIDEO_SWITCH) == 0)        /* Holding Video switch enters RSSI calibration mode. */
    {
        AutoRSSIMode = true;
    }

    else
    {
        AutoRSSIMode = false;
    }


    if(DebugMode == true)
    {
        Serial.begin(19200);                    /* Start serial terminal if in debug mode. */
        Serial.println(" ");
        Serial.println(" ");
        Serial.println("Div4RX5808-PRO");
        Serial.println("Dual 5.8GHz Video Receiver Diversity Controller with RX5808-PRO functionality.");
        Serial.println("SlyMike");
        Serial.println(" ");
        Serial.println(" ");
        Serial.print(AUTHOR);
        Serial.print(", V");
        Serial.print(INFO_MAJOR_VERSION);
        Serial.print(".");
        Serial.println(INFO_MINOR_VERSION);

        Serial.print(COMPILE_DATE);
        Serial.print(" - ");
        Serial.println(COMPILE_TIME);
        Serial.println(SOURCE_FILE);
        Serial.print("Compiled with = ");
        Serial.println(COMPILER);

        Serial.println(" ");
        Serial.println("!!!DEBUG MODE!!!");
        Serial.println(" ");
        delay(200);

        if(AutoRSSIMode == true)
        {
            Serial.println("!!!AUTO RSSI CALIBRATION MODE!!!");
            Serial.println(" ");
            delay(200);
        }

        else
        {
        /* Do Nothing */
        }
    }
}



/*******************************************************************************
loop

*******************************************************************************/
void loop()
{
    digitalWrite(LED_HEARTBEAT, HIGH);



    /*******************************************************************************
    VIDEO TOGGLING SECTION

    Selects video source on selected video receiver. Each receiver has two video
    outputs, live video and spectrum analyser.
    *******************************************************************************/



    VideoSwitchReading = digitalRead(VIDEO_SWITCH);  /* Read the value of the video switch and save */
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

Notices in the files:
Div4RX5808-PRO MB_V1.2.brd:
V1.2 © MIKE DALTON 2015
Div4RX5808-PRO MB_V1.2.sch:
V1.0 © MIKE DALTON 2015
